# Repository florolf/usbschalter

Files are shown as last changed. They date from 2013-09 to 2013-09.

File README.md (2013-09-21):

# Purpose

In our hackerspace [RFID dooropener project](https://github.com/entropia/tuerd),
we encountered the problem that the RFID reader would randomly lock up so badly
that only disconnecting and reconnecting it to USB would help. While locking
up could be detected in software, nothing could be done except sending out an
alert and hoping that someone would manually powercycle the reader. This project
attempts to fix this. It allows another piece of software to physically
disconnect and reconnect an USB device.

# Usage

The daemon is meant to be run by some service supervision scheme like
daemontools or [runit](http://smarden.org/runit/). It attaches itself to the
FTDI device (should you have more than one FTDI device present, you'll probably
have to change the VID/PID of one of them to disambiguate) and waits for one of
the following signals in a loop:

* <code>SIGUSR1</code> will turn the device on
* <code>SIGUSR2</code> will turn the device off
* <code>SIGHUP</code> will turn the device off, wait 2 seconds and turn the
  device on again

When the daemon is started, the device will be turned on.

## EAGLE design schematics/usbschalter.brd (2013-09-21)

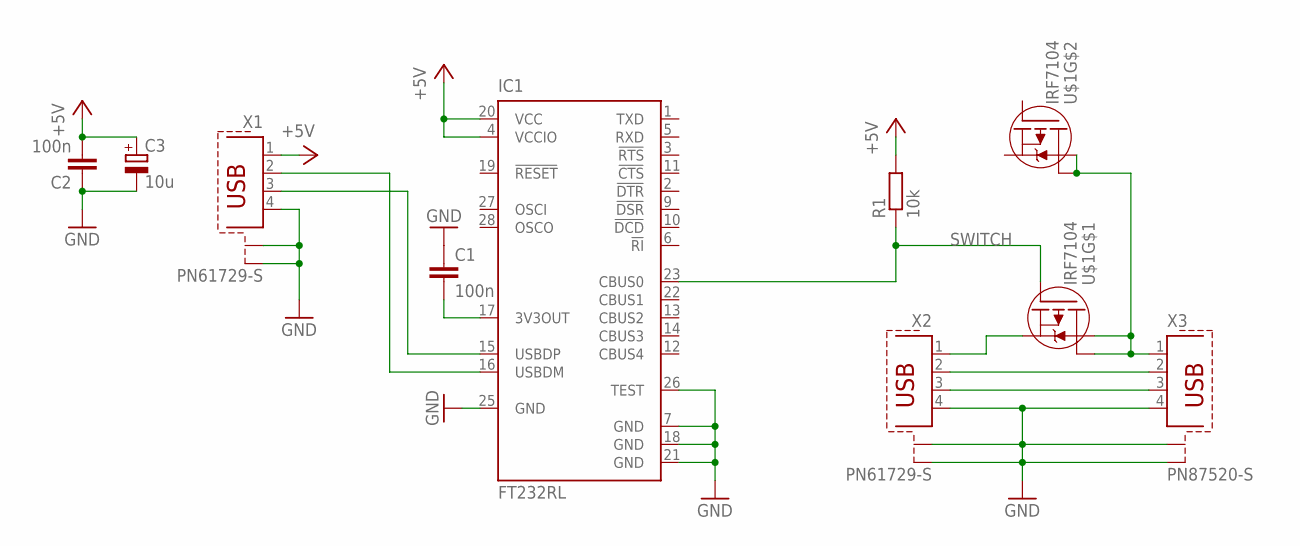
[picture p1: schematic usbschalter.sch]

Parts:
C1, C2: 100n; C0805
C3: 10u; E1,8-4
IC1: FT232RL; SSOP28
R1: 10k; R0805
U$1: IRF7104; SO8-2
X1, X2: PN61729-S
X3: PN87520-S

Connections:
+5V: C2.2, C3.+, IC1.4 (VCCIO), IC1.20 (VCC), R1.2, X1.1
GND: C1.1, C2.1, C3.-, IC1.7 (GND), IC1.18 (GND), IC1.21 (GND), IC1.25 (GND), IC1.26 (TEST), X1.4, X1.S1, X1.S2, X2.4, X2.S1, X2.S2, X3.4, X3.S1, X3.S2
unnamed: X2.3, X3.3
unnamed: X2.2, X3.2
unnamed: U$1.1 (S), X2.1
unnamed: IC1.16 (USBDM), X1.2
unnamed: IC1.15 (USBDP), X1.3
unnamed: U$1.5 (D), U$1.6 (D), U$1.7 (D), U$1.8 (D), X3.1
unnamed: C1.2, IC1.17 (3V3OUT)
SWITCH: IC1.23 (CBUS0), R1.1, U$1.2 (G)

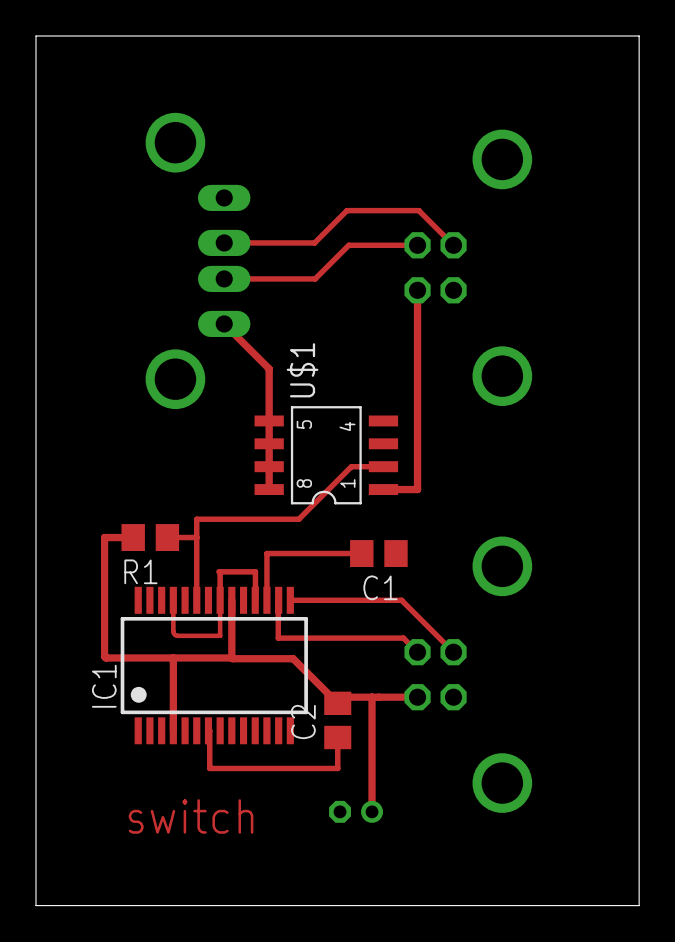
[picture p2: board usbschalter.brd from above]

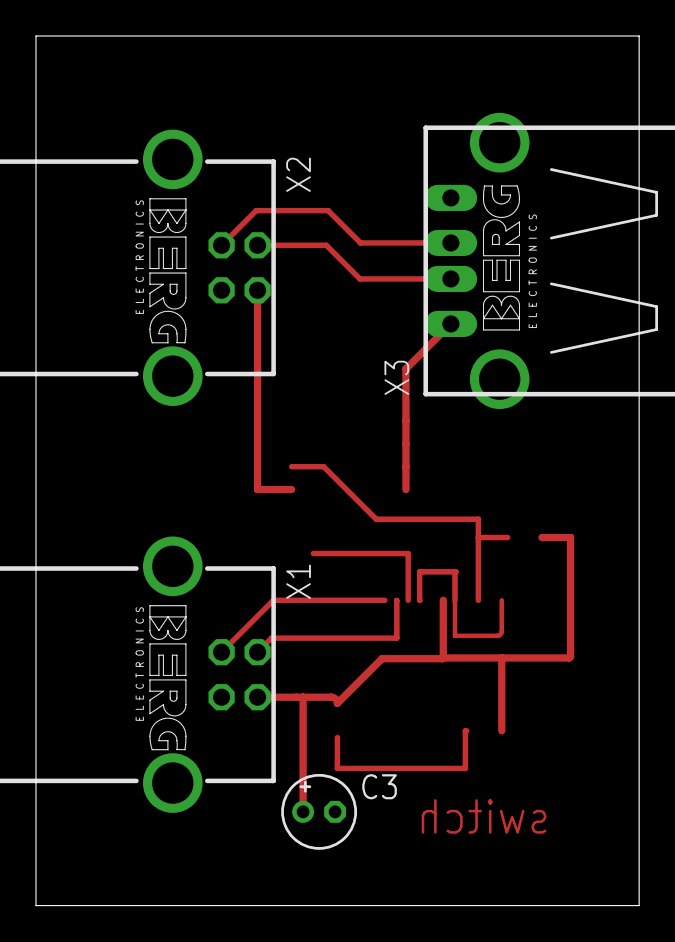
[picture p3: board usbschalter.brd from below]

Board: 2 copper layers, 33.5 x 48.3 mm, 9 parts (4 on the bottom side), 10 nets.

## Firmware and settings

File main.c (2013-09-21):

#include <stdio.h>
#include <stdbool.h>
#include <unistd.h>
#include <stdlib.h>
#include <ftdi.h>
#include <signal.h>

#define SCHALTER_VID 0x0403
#define SCHALTER_PID 0x6001

enum action {
	ON, OFF, CYCLE, IDLE
};

struct ftdi_context ftdi;
volatile enum action action = IDLE;

void handler(int sig) {
	switch(sig) {
		case SIGUSR1:
			action = ON;
			break;
		case SIGUSR2:
			action = OFF;
			break;
		case SIGHUP:
			action = CYCLE;
			break;
	}
}

void open_ftdi(void) {
	int f = ftdi_usb_open(&ftdi, SCHALTER_VID, SCHALTER_PID);
	if(f < 0) {
		fprintf(stderr, "ftdi_usb_open failed: %s\n", ftdi_get_error_string(&ftdi));
		exit(1);
	}
}

void reopen_ftdi(void) {
	int f = ftdi_usb_close(&ftdi);
	if(f < 0) {
		fprintf(stderr, "ftdi_usb_close failed: %s\n", ftdi_get_error_string(&ftdi));
		exit(1);
	}

	open_ftdi();
}

void set_usb(bool state) {
	int bitmask = 0x10 | (state ? 0 : 1);

	fprintf(stderr, "setting output to %s\n", state ? "ON" : "OFF");

	while(ftdi_set_bitmode(&ftdi, bitmask, BITMODE_CBUS) < 0) {
		fprintf(stderr, "ftdi_set_bitmode failed: %s\n", ftdi_get_error_string(&ftdi));
		reopen_ftdi();

		sleep(1);
	}
}

int main(int argc, char **argv) {
	fprintf(stderr, "usbschalter starting up\n");

	struct sigaction sa;
	sa.sa_handler = handler;
	sigemptyset(&sa.sa_mask);
	sa.sa_flags = 0;

	sigaction(SIGUSR1, &sa, NULL);
	sigaction(SIGUSR2, &sa, NULL);
	sigaction(SIGHUP, &sa, NULL);

	ftdi_init(&ftdi);
	open_ftdi();

	set_usb(true);

	while(1) {
		pause();

		switch(action) {
			case OFF:
				set_usb(false);
				break;
			case ON:
				set_usb(true);
				break;
			case CYCLE:
				set_usb(false);
				sleep(2);
				set_usb(true);
				break;
			default:
				fprintf(stderr, "unhandled signal received\n");
				break;
		}

		action = IDLE;
	}

}

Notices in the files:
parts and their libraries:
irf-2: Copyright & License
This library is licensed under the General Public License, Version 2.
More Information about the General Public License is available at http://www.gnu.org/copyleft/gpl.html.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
